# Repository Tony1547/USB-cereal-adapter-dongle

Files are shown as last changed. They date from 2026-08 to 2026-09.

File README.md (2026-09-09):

# USB-cereal-adapter-dongle
USB-cereal-adapter-dongle
-----

I plan to make more PCB projects, so I'm making this to hopefully program them, also i hope to get better at soldering through this project 

This dongle uses the CH340C to communicate from USB to UART, and can be hung from a small keychain with the hole in the corner, also includes some personalization on the back of things that relate to me or the ysws

----











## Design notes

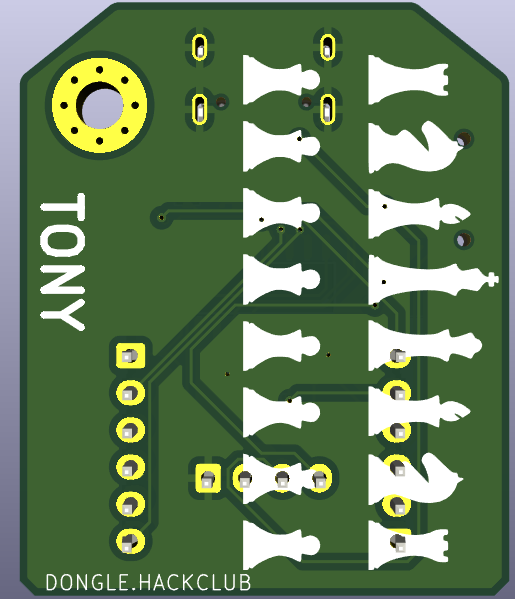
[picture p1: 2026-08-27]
Images/Screenshot_2026-08-27_03-43-29.png

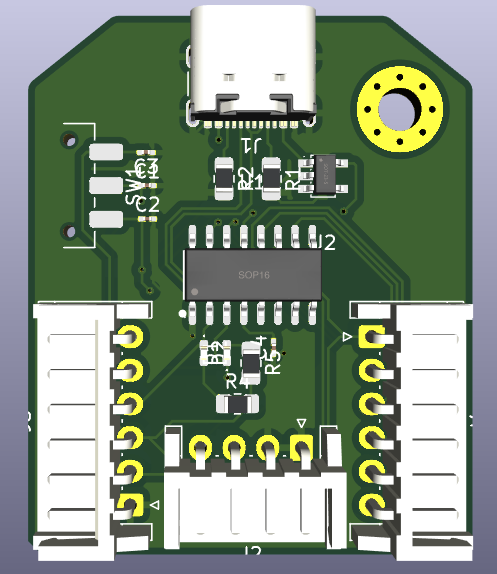
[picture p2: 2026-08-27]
Images/Screenshot_2026-08-27_03-42-09.png

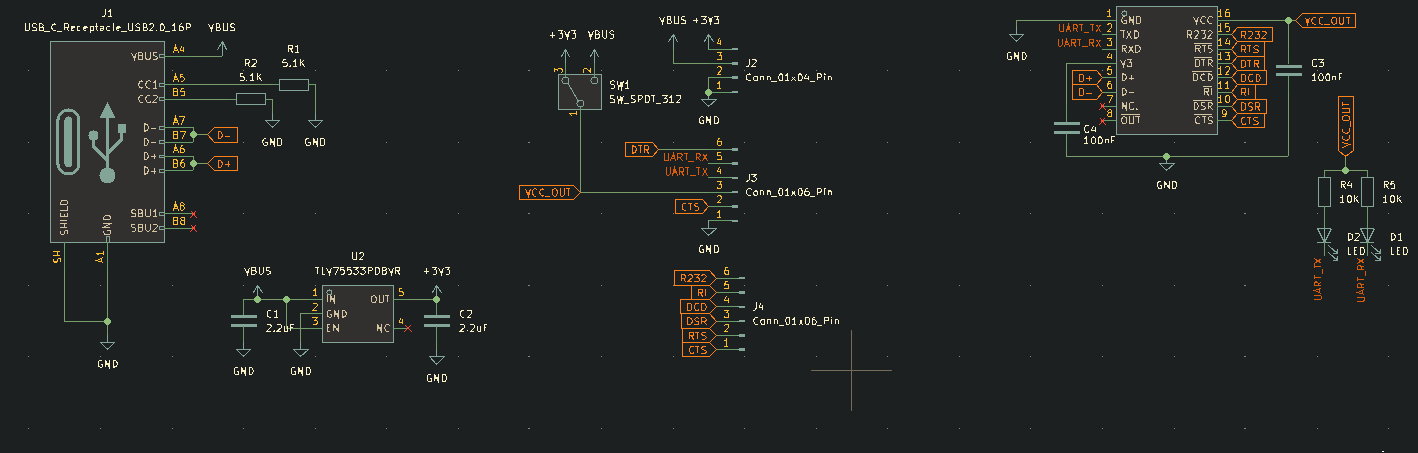
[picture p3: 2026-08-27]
Images/Screenshot_2026-08-27_03-44-53.png

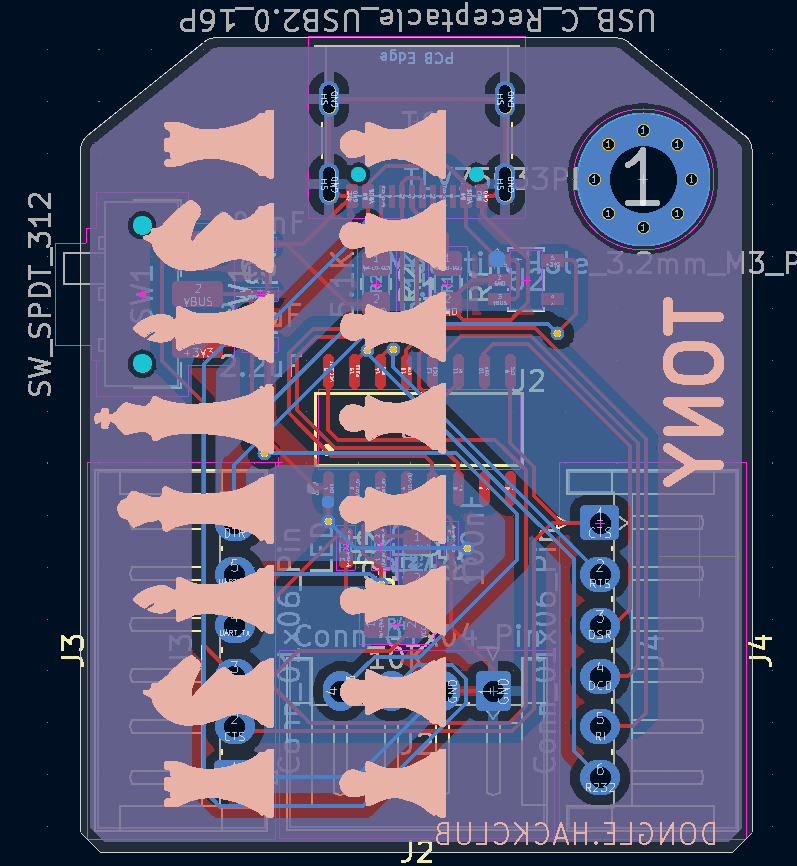
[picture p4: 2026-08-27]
Images/Screenshot_2026-08-27_03-42-06.png

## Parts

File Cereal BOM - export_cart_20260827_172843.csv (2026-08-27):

Index | LCSC# | MPN | Manufacturer | Package | Customer # | Description | RoHS | Quantity | MOQ | Multiple | Unit Price($) | Extended Price($) | Product Link
1 | C20089287 | S6B-EH | JST | Through Hole,P=2.5mm |  | Connector Header 6 position 2.5mm Pitch 3A Right Angle -25℃~+85℃ | yes | 2 | 1 | 1 | 0.1963 | 0.39 | https://www.lcsc.com/product-detail/C20089287.html
2 | C27834 | 0805W8F5101T5E | UNI-ROYAL | 805 |  | 5.1kΩ ±1% 125mW 0805 Thick Film Resistor | yes | 100 | 100 | 100 | 0.0113 | 1.13 | https://www.lcsc.com/product-detail/C27834.html
3 | C2907219 | FRC0805F1002TS | FOJAN | 805 |  | 10kΩ ±1% 125mW 0805 Thick Film Resistor | yes | 100 | 100 | 100 | 0.0035 | 0.35 | https://www.lcsc.com/product-detail/C2907219.html
4 | C84681 | CH340C | WCH | SOP-16 |  | Transceiver 2Mbps USB 2.0 SOP-16 Interface Controllers | yes | 1 | 1 | 1 | 0.5879 | 0.59 | https://www.lcsc.com/product-detail/C84681.html
5 | C404027 | TLV75533PDBVR | TI | SOT-23-5 |  | 3.3V Positive Fixed SOT-23-5 Voltage Regulators - Linear, Low Drop Out (LDO) Regulators RoHS | yes | 5 | 5 | 5 | 0.1636 | 0.82 | https://www.lcsc.com/product-detail/C404027.html
6 | C23630 | CL10A225KO8NNNC | Samsung Electro-Mechanics | 603 |  | 2.2uF ±10% 16V Ceramic Capacitor X5R 0603 | yes | 50 | 50 | 50 | 0.0196 | 0.98 | https://www.lcsc.com/product-detail/C23630.html
7 | C6119867 | CGA0603X7R104K500JT | HRE | 603 |  | 100nF ±10% 50V Ceramic Capacitor X7R 0603 | yes | 100 | 100 | 100 | 0.0066 | 0.66 | https://www.lcsc.com/product-detail/C6119867.html
8 | C963206 | MK-12C02-G020 | G-Switch | SMD,6.6x1.4mm |  | Slide Switch SPDT 1A @ 6V Surface Mount, Right Angle Rectangular Columnar 6.6mm | yes | 5 | 5 | 5 | 0.1245 | 0.62 | https://www.lcsc.com/product-detail/C963206.html
9 | C22355736 | XL-1005UBC | XINGLIGHT | 402 |  | Blue 465nm LED Indication - Discrete 3.3V 0402 | yes | 50 | 50 | 50 | 0.008 | 0.4 | https://www.lcsc.com/product-detail/C22355736.html
10 | C165948 | TYPE-C-31-M-12 | Korean Hroparts Elec | SMD |  | USB-C (USB TYPE-C) Receptacle Connector 16 Position Surface Mount | yes | 5 | 5 | 5 | 0.1716 | 0.86 | https://www.lcsc.com/product-detail/C165948.html
 |  |  |  |  |  |  |  |  |  |  |  | 6.8
 |  |  |  |  |  |  |  |  |  |  |  | $18.75 + shipping
 |  |  |  |  |  |  |  |  |  |  |  | $10.18 for PCB

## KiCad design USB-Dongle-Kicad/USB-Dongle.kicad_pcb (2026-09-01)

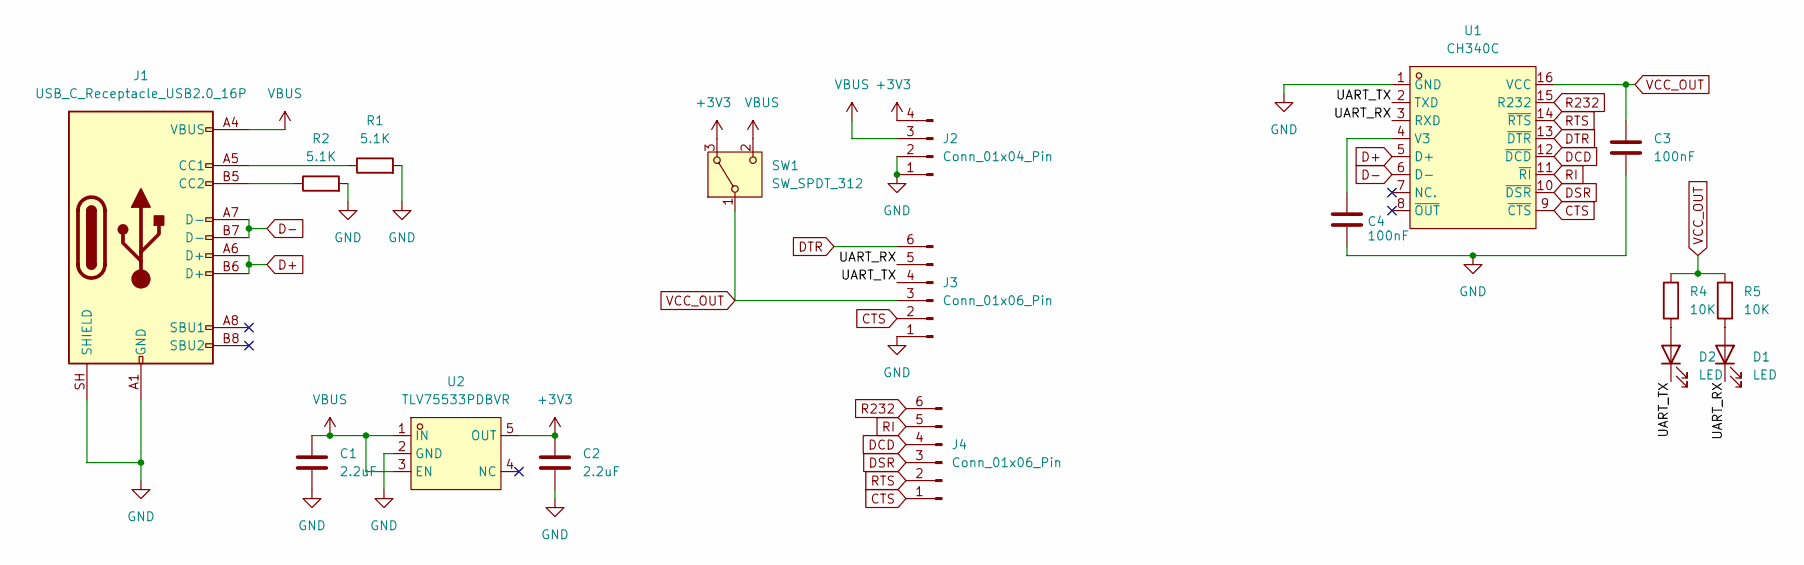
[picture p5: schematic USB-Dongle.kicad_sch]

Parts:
C1, C2: 2.2uF; C_0603_1608Metric_Pad1.08x0.95mm_HandSolder
C3, C4: 100nF; C_0603_1608Metric_Pad1.08x0.95mm_HandSolder
D1, D2: LED; LED_0402_1005Metric_Pad0.77x0.64mm_HandSolder
J1: USB_C_Receptacle_USB2.0_16P; USB_C_Receptacle_GCT_USB4105-xx-A_16P_TopMnt_Horizontal
J2: Conn_01x04_Pin; JST_EH_S4B-EH_1x04_P2.50mm_Horizontal
J3, J4: Conn_01x06_Pin; JST_EH_S6B-EH_1x06_P2.50mm_Horizontal
R1, R2: 5.1K; R_0805_2012Metric_Pad1.20x1.40mm_HandSolder
R4, R5: 10K; R_0805_2012Metric_Pad1.20x1.40mm_HandSolder
SW1: SW_SPDT_312; SW_SPDT_CK_JS102011SAQN
U1: CH340C; SOP-16_L10.0-W3.9-P1.27-LS6.0-BL; MPN CH340C; LCSC Part C84681
U2: TLV75533PDBVR; SOT-23-5_L3.0-W1.7-P0.95-LS2.8-BR; MPN TLV75533PDBVR; LCSC Part C404027

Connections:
+3V3: C2.1, J2.4, SW1.3 (A), U2.5 (OUT)
/UART_RX: D1.1 (K), J3.5, U1.3 (RXD)
/UART_TX: D2.1 (K), J3.4, U1.2 (TXD)
CTS: J3.2, J4.1, U1.9 (~CTS)
D+: J1.A6 (D+), J1.B6 (D+), U1.5 (D+)
D-: J1.A7 (D-), J1.B7 (D-), U1.6 (D-)
DCD: J4.4, U1.12 (~DCD)
DSR: J4.3, U1.10 (~DSR)
DTR: J3.6, U1.13 (~DTR)
GND: C1.2, C2.2, C3.1, C4.1, J1.A1 (GND), J1.A12 (GND), J1.B1 (GND), J1.B12 (GND), J1.SH (SHIELD), J2.1, J2.2, J3.1, R1.2, R2.2, U1.1 (GND), U2.2 (GND)
unnamed: D1.2 (A), R5.1
unnamed: D2.2 (A), R4.1
unnamed: J1.A5 (CC1), R1.1
unnamed: J1.B5 (CC2), R2.1
unnamed: C4.2, U1.4 (V3)
R232: J4.6, U1.15 (R232)
RI: J4.5, U1.11 (~RI)
RTS: J4.2, U1.14 (~RTS)
VBUS: C1.1, J1.A4 (VBUS), J1.A9 (VBUS), J1.B4 (VBUS), J1.B9 (VBUS), J2.3, SW1.2 (C), U2.1 (IN), U2.3 (EN)
VCC_OUT: C3.2, J3.3, R4.2, R5.2, SW1.1 (B), U1.16 (VCC)

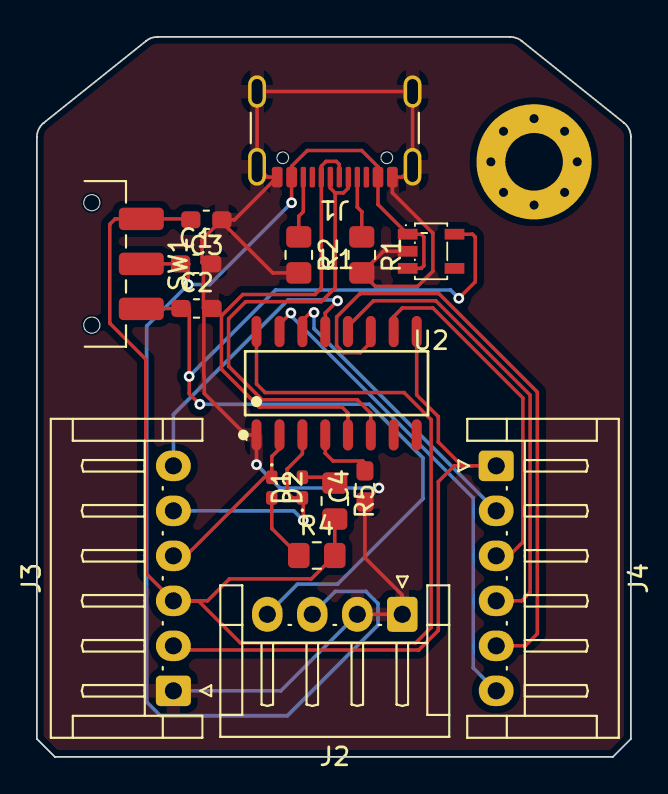
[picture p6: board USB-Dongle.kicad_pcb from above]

Board: 2 copper layers, 33.0 x 40.0 mm, 17 parts (0 on the bottom side), 20 nets.

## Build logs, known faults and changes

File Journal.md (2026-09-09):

# USB-Cereal-Adapter

**I plan to make more PCB projects, so I'm making this to hopefully program them, also i hope to get better at soldering through this project**

----

I procrastinated so I did the whole project in a 3hr session at 1:00am, and I'm writing this after I woke up ans sleeping. 

Originally I accidentally used a 0201 capacitors when i meant to use 0603, and when uploading my gerbers to JLCPCB the first time I forgot to generate the drill files. But that's all fixed now :D







I used JST connectors for the sole reason that I think they look cool, is it the most practical? Probably not but very nice looking. The hole in the top right is to put it on some string and then onto a keychain, and the chess silkscreen is there because I love to play chess, really cool game imo. I plan to plug this into my laptop through a USB-C to USB-C cable, I usually carry one in my bag. (at the time of writing this only one of the USB-C ports work so I need to fix that at some point)



I used the CH340C because its cheap and built the rest of the board around it, I also thought it would be cool to be able to switch between 5V and 3.3 Volts and that's why there is a switch on it. Hopefully it works, I'm still not great at PCB design yet so I'm still learning a lot. 



Next time I make something small like this I need to make a funnier shape, like a doctor pepper can or a coffee, or smt. The main lesson of this project however for me is to better plan out when I work on projects so I don't end up being sleep deprived the next day... or maybe not, who knows. One more thing I want to keep in mind or at least practice in-between this PCB project and my next is packaging, I think this board could've definitely been smaller, and smaller is usually cheaper. I think.



9/7
-------

didn't add enough info about the project in the repo so I've been adding more little by little, 

spent 30ish minutes fixing up the repo, adding missing 3d models, updating pictures, and changing the size of some of the SMD parts in kicad to match my BOM

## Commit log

2026-08-27 upload kicad
    [USB-Dongle-B_Cu.gbr, USB-Dongle-B_Mask.gbr, USB-Dongle-B_Paste.gbr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]
2026-08-27 Updated stuff
    [Cereal BOM - export_cart_20260827_172843.csv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]
2026-09-01 add 3d models
    [USB-Dongle-B_Cu.gbr, USB-Dongle-B_Mask.gbr, USB-Dongle-B_Paste.gbr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]
